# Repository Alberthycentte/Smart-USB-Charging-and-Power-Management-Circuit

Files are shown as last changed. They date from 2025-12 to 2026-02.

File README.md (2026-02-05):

This custom-designed circuit board manages power distribution between a USB source, a rechargeable battery, and an external load. When connected to a USB power source, the circuit intelligently routes power to the load while charging the battery in parallel. Once the USB is disconnected, it seamlessly switches to battery power, ensuring uninterrupted operation of the connected device.

The design includes an onboard LED indicator that displays the charging status, making it easy to monitor battery activity at a glance. The compact layout and use of surface-mount components allow for efficient space utilization while maintaining clear signal routing and reliable performance.

Key Features

Automatic power path control between USB and battery

Simultaneous load powering and battery charging

Seamless switching to battery when USB is disconnected

LED indicator for real-time charging status

Compact and efficient PCB layout

Applications

This is deal for portable electronics, sensor modules, or any embedded system requiring a stable power supply with automatic source selection.

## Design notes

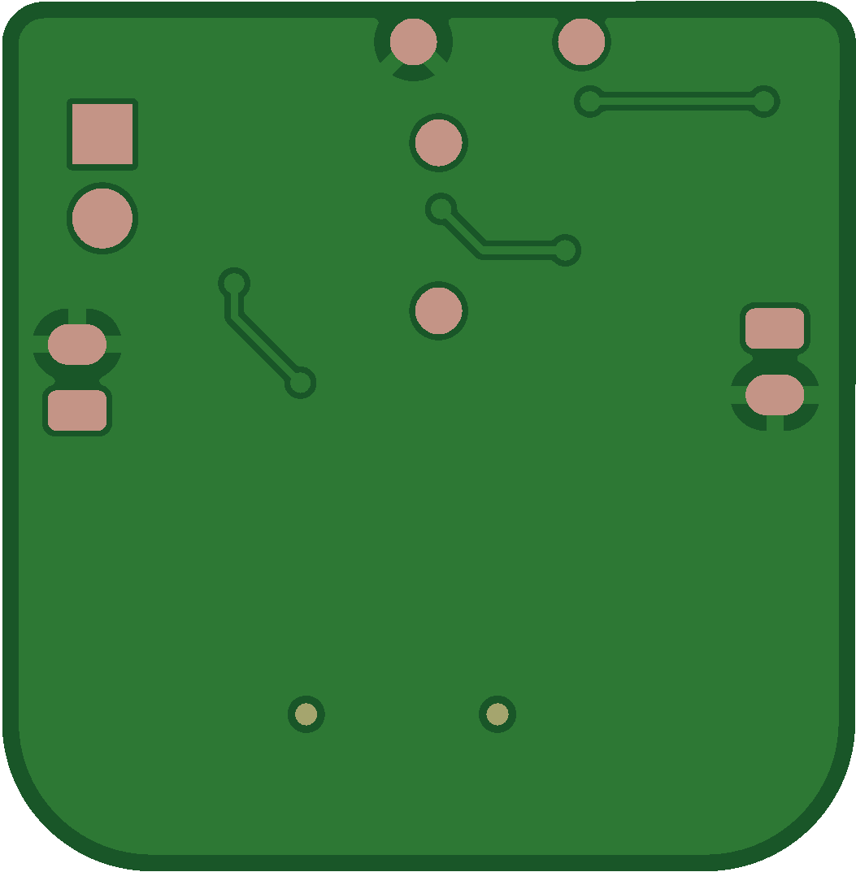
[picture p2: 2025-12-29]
simulation_image_bottom.png

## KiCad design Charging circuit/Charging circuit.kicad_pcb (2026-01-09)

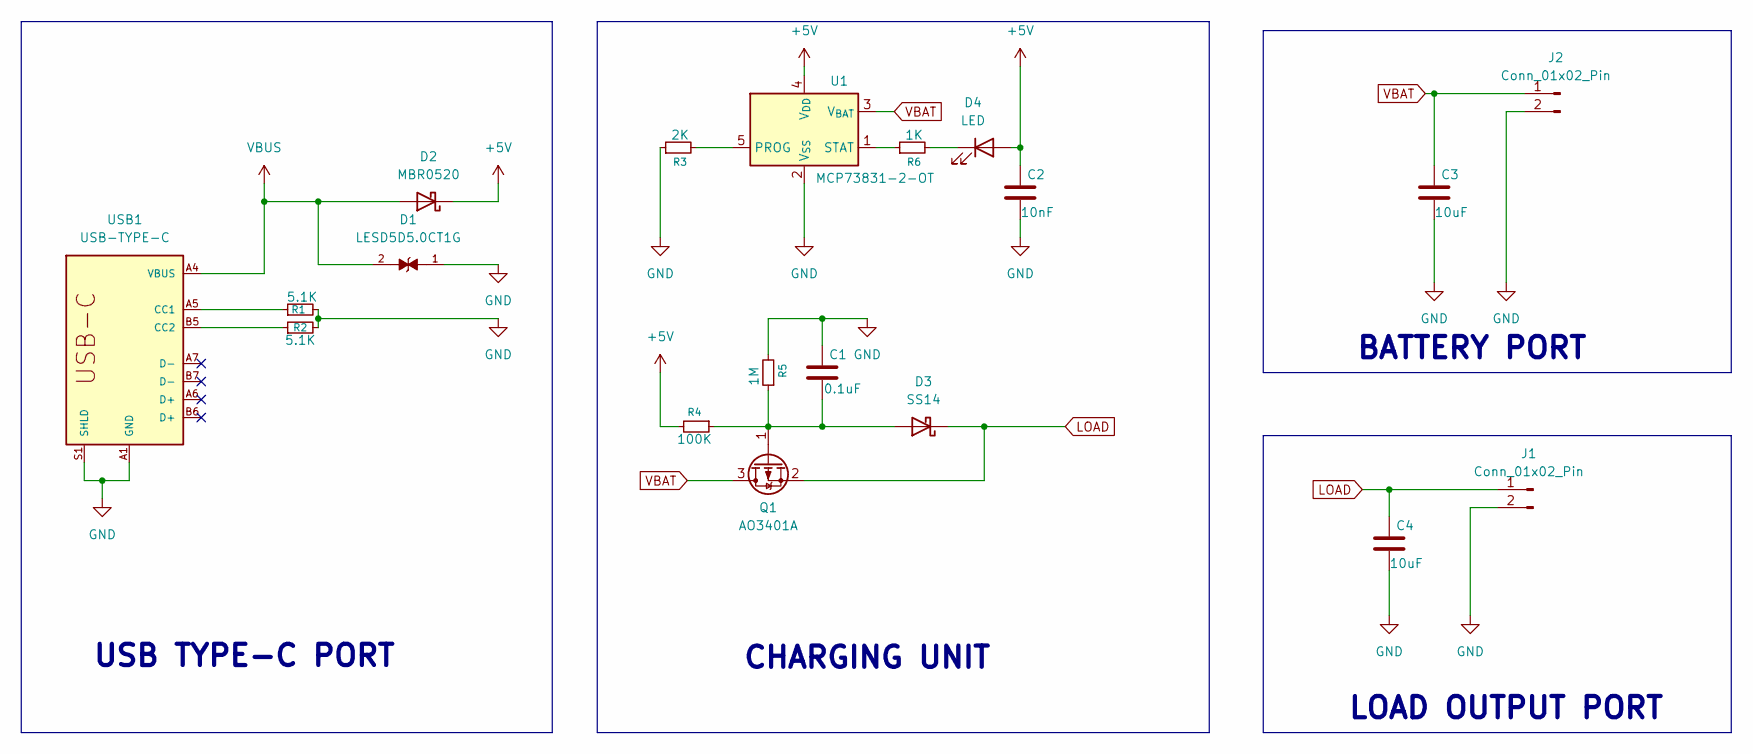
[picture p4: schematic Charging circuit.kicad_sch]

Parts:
C1: 0.1uF; C_0805_2012Metric
C2: 10nF; C_0805_2012Metric
C3, C4: 10uF; C_0805_2012Metric
D1: LESD5D5.0CT1G; TVS_LESD5D5.0CT1G; PARTREV O
D2: MBR0520; D_SOD-123
D3: SS14; D_SMA
D4: LED; LED_D3.0mm_Horizontal_O1.27mm_Z6.0mm
J1, J2: Conn_01x02_Pin; JST_PH_B2B-PH-K_1x02_P2.00mm_Vertical
Q1: AO3401A; SOT-23
R1, R2: 5.1K; R_0805_2012Metric
R3: 2K; R_0805_2012Metric
R4: 100K; R_Axial_DIN0204_L3.6mm_D1.6mm_P5.08mm_Horizontal
R5: 1M; R_Axial_DIN0204_L3.6mm_D1.6mm_P5.08mm_Horizontal
R6: 1K; R_0805_2012Metric
U1: MCP73831-2-OT; SOT-23-5
USB1: USB-TYPE-C; USBC.USB4110-GF-A

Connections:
+5V: C2.1, D2.1 (K), D4.2 (A), R4.2, U1.4 (V_{DD})
GND: C1.1, C2.2, C3.2, C4.2, D1.1, J1.2, J2.2, R1.2, R2.2, R3.1, R5.2, U1.2 (V_{SS}), USB1.A1 (GND), USB1.S1 (SHLD)
LOAD: C4.1, D3.1 (K), J1.1, Q1.2 (S)
unnamed: C1.2, D3.2 (A), Q1.1 (G), R4.1, R5.1
unnamed: D4.1 (K), R6.2
unnamed: R3.2, U1.5 (PROG)
unnamed: R6.1, U1.1 (STAT)
unnamed: R1.1, USB1.A5 (CC1)
unnamed: R2.1, USB1.B5 (CC2)
VBAT: C3.1, J2.1, Q1.3 (D), U1.3 (V_{BAT})
VBUS: D1.2, D2.2 (A), USB1.A4 (VBUS)

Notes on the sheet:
USB TYPE-C PORT
BATTERY PORT
LOAD OUTPUT PORT
CHARGING UNIT

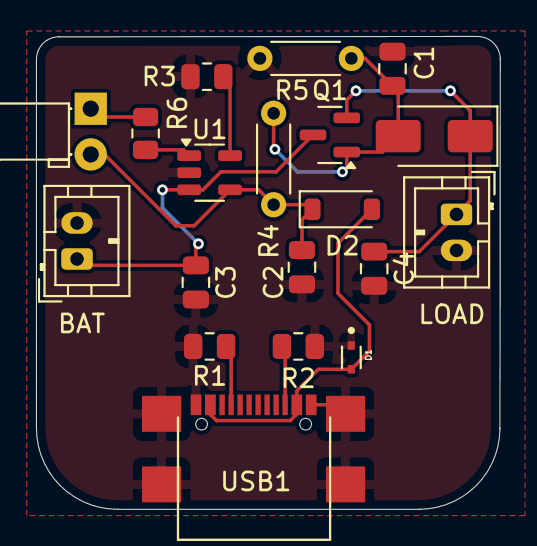
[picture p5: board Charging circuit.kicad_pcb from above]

Board: 2 copper layers, 25.8 x 26.3 mm, 19 parts (0 on the bottom side), 11 nets.
